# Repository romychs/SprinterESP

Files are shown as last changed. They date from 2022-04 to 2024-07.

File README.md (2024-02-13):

# Sprinter Wi-Fi

Проект ISA-8 платы для подключения Wi-Fi модуля ESP8266 к персональному любительскому компьютеру Sprinter.

Программное обеспечение, в настоящее время, в разработке.

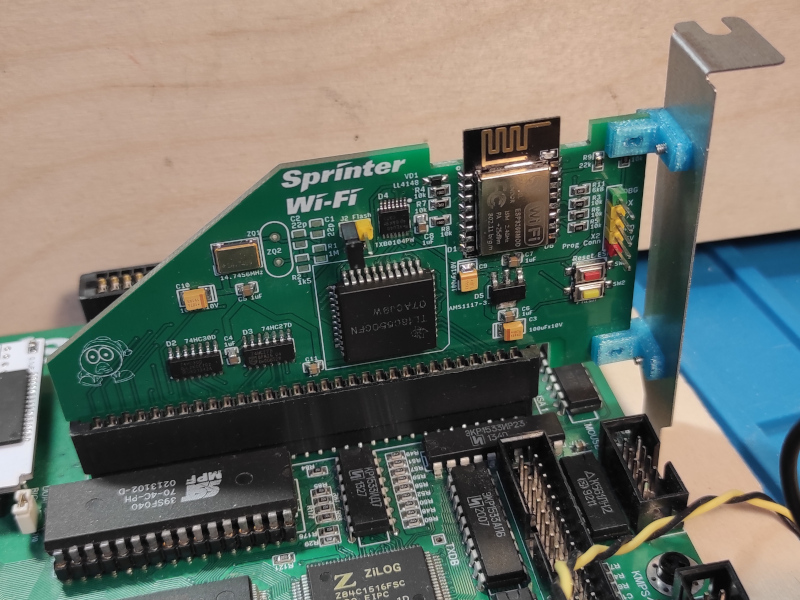
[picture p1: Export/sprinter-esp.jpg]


[Принципиальная схема](Export/Schematic_Sprinter-ESP_v1.0.4.pdf)

[Монтажная схема](Export/PCB_Sprinter-ESP-v1.0.4.pdf)

[Спринтер в Телеграм](https://t.me/zx_sprinter)

[Спринтер в Web](https://www.sprinter.ru/)

Часто, модули с Ali идут без прошивки ESP-AT. В таком виде карта Sprinter Wi-Fi работать не будет, модуль ESP нужно прошить. Инструкция в [документе](Docs/ESP-module-flashing.pdf).

## Изменения
* _v1.0.3_ Устранена ошибка с перепутанными сигналами RTS и CTS. В [документе](Docs/rts-cts-fix.pdf) описано, как это исправить на старых версиях платы.
* _v1.0.4_ Добавлен контакт VCC на разъеме X2 для подачи напряжения 5В при программировании ESP через внешний USB-TTL UART адаптер.
* _v1.0.5_ Косметические изменения для удобства пайки.

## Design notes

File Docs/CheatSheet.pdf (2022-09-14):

Порты UART
Порт ISA COM3 | 0x03E8
Базовый адрес портов карты ISA в
памяти

0xC3E8

Регистры UART
DLAB | A2 | A1 | A0 | Регистр
0 | 0 | 0 | 0 | RBR Read Buffer Reg, RO
0 | 0 | 0 | 0 | THR Transmitter hold reg, WO
0 | 0 | 0 | 1 | IER Interrupt enable reg
x | 0 | 1 | 0 | IIR Interrupt id reg, RO
x | 0 | 1 | 0 | FCR FIFO Control reg, WO
x | 0 | 1 | 1 | LCR Line Control reg
x | 1 | 0 | 0 | MCR Modem Contril reg
x | 1 | 0 | 1 | LSR Line Status reg
x | 1 | 1 | 0 | MSR Modem Status reg
x | 1 | 1 | 1 | SCR Scratch reg
1 | 0 | 0 | 0 | DLL Divisor latch LSB
1 | 0 | 0 | 1 | DLM Divisor latch MSB

LCR
1-0 00 — 5 bit data
01 — 6 bit data
10 — 7 bit data
11 — 8 bit data
2 | 0 — 1 stop bit
1 — 1,5 stop bits
3 | 0 — Disable parity, 1 — enable
4 | 0 — odd, 1 — even
5 | Stich patity 0 — dis, 1 -en
6 | break 0 — dis, 1 — en
7 | DLAB 0 — access receiver buffer; 1 -
access divisor latch

LSR
0 | DR Data Ready
1 | OE Overrun Error
2 | PE Parity Error
3 | FE Frame Error
4 | BI Break Interrupt
5 | THRE Transmitter Holding Register
6 | TEMT Transmitter Empty
7 | Error in RCVR FIFO

FCR
0 | FIFO Enable
1 | Receiver FIFO reset
2 | Transmitter FIFO reset
3 | DMA mode select
4 | reserved
5 | reserved
6 | Receiver trigger LSB
7 | Receiver trigger MSB

MCR
0 | DTR
1 | RTS
2 | OUT1 (Reset ESP)
3 | OUT2 (Program ESP)
4 | Loop
5 | AFE Autoflow control enable
6 | 0
7 | 0

IIR
0 | 0 — no pending interrupt
1 | Int ID bit 1
2 | Int ID bit 2
3 | Int ID bit 3
4 | 0
5 | 0
7-6 | Enable FIFOs int trigger lvl

Команды ESP AT
AT+RST | Сброс
AT+GMR | Получение версии прошивки
Wi-Fi
AT+CWMODE=1 | Включить режим станции
AT+CWJAP="SSID",
"password"

Подключение к сети

AT+CWLAP | Список доступных сетей
AT+CWQAP | Отсоединение от сети
AT+CWDHCPS? | Получить статус DHCP
AT+CWAUTOCONN=1 | Включить автоподключение к
WiFi. 0 — выкл.
AT+CIFSR | Показать IP-адрес
TCP/IP
AT+CIPSTATUS | Статус TCP/IP. 4-откл; 3-
подкл; 2-получен IP адр.
UART
ATE0 | Отключить эхо
AT+UART_CUR=1152 00,8,1,0,3 | Включить сколость 115200, 8 бит данных, без контроля четности,1 стоп-бит, RTS/CTS

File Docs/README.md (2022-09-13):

# Sprinter Wi-Fi

Инструкции к карте Sprinter Wi-Fi.

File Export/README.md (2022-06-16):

# Sprinter Wi-Fi

Схема и печатная плата в доступных для просмотра форматах.

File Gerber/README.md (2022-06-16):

# Sprinter Wi-Fi

При заказе платы, не забудте указать, что плата имеет контакты на краю платы и нужен скос, для удобства вставки платы в слот.

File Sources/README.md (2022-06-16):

# Sprinter Wi-Fi

Исходники проекта в [EasyIDA:](https://easyeda.com/)

*Как использовать:*

В редакторе, кликнуть на тулбаре в меню "Document" > "Open" > "EasyEDA Source", и выберите json-файл.

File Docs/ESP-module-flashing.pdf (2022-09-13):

# Прошивка модуля ESP-12 на карте Sprinter Wi-Fi

## Подключение

Для правильной работы карты Sprinter W-iFi, модуль, ESP-12 должен имень прошивку ESP-AT. Для прошивки понадобится преобразователь (адаптер) USB-UART, иногда они называются USB-TTL, их много на Ali, пойдет практически любой, с выходами, на 3,3В. Я пользуюсь преобразователями с чипами CH340, SiliconLabs CP210x. Драйверы для них уже встроены в Windows 10, Linux, ну и их не проблема найти для более старых версий Windows.

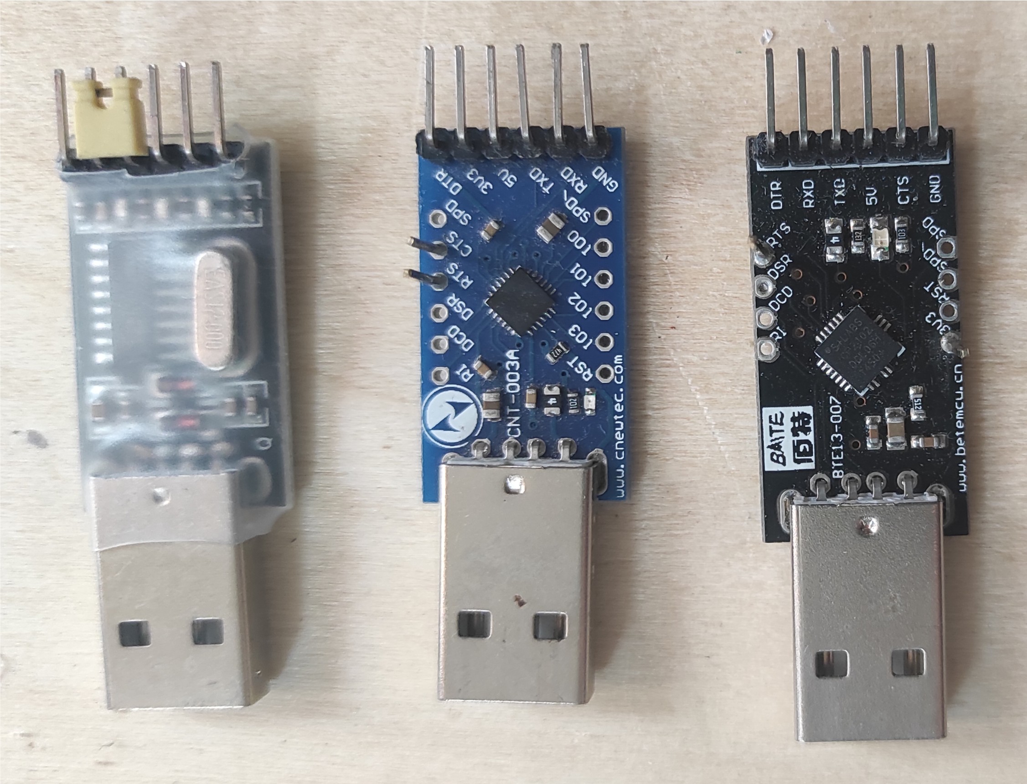
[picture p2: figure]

Подключаем преобразователь USB-UART к плате Sprinter Wi-Fi к разъему X2 (ProgConn) следующим образом:
TX → TX, RX→RX, GND→GND

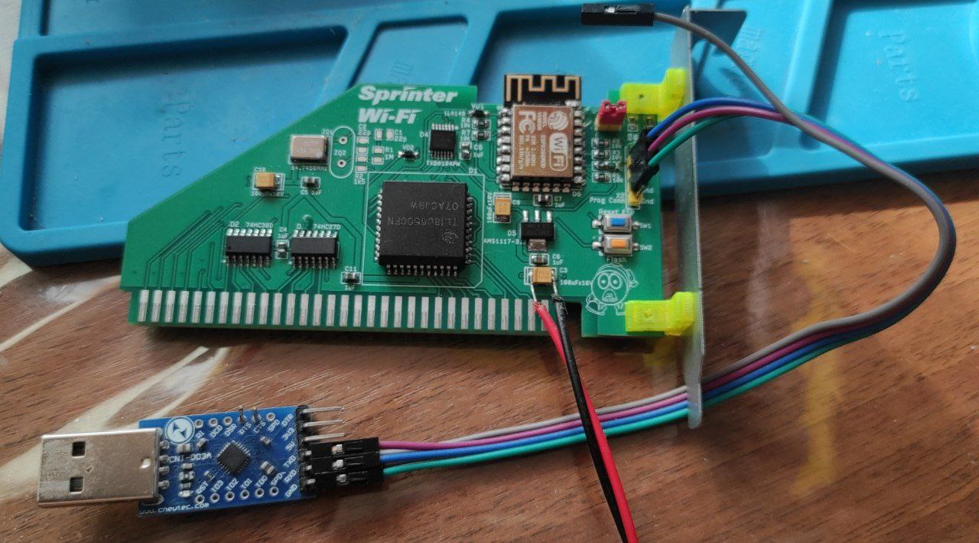
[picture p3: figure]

На плату Sprinter Wi-Fi нужно подать питание 5В. Можно запитать плату от слота самого Sprinter-а, можно временно подать питание, подпаявшись к электролитическому конденсатору C3. Не путайте полярность.

## Прошивка

Для прошивки ESP существует специальное ПО, от фирмы Espressif, называется оно Flash Download Tool. Найти его можно на сайте производителя, https://www.espressif.com/en/support/download/other-tools
Установки оно не требует, нужно просто скачать архив, распаковать и запустить исполняемый файл (flash_download_tool_x.x.x.exe).
Так же потребуются и файлы AT-firmware для прошивки модуля ESP. Найти более-менее свежий, подходящий для нашего модуля софт не простоб но можно. В архиве ESP8266_AT_V2.2.1.7z прилагается тот, который шью в модуль я. Мне удалось собрать и самую свежую прошивку, но я ее пока тестирую. Архив распакуйте в отдельную папку. Теперь подключаем питание к SprinterWiFi, вставляем адаптер USB-UART в USB-порт компьютера. Смотрим в диспетчере устройств, на каком COM-порту он работает:

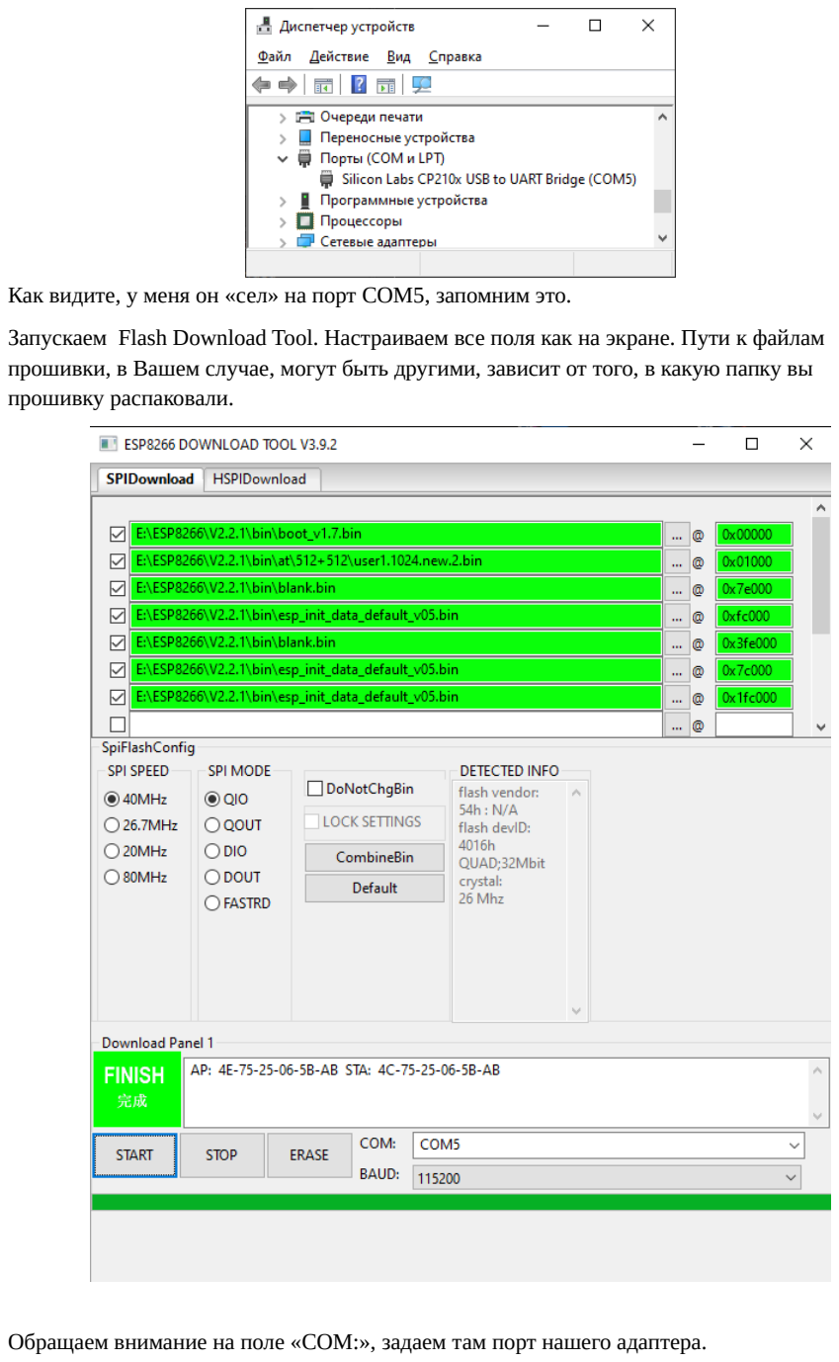
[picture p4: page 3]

Как видите, у меня он «сел» на порт COM5, запомним это.
Запускаем Flash Download Tool. Настраиваем все поля как на экране. Пути к файлам прошивки, в Вашем случае, могут быть другими, зависит от того, в какую папку вы прошивку распаковали.

Обращаем внимание на поле «COM:», задаем там порт нашего адаптера.

Теперь нажимаем кнопку Start, программа перейдет в режим прграммирования и будет ждать ESP.
Теперь переводим нашу карточку Sprinter Wi-Fi в режим программирования ESP:
1. Замыкаем джампер J2 (Flash) (Его расположение на плате может отличаться, в зависимости от версии)
2. Нажимаем кнопки SW1 + SW2
3. Отпускаем SW1 (Reset)
4. Через секунду-другую, отпускаем SW2 (Flash)
После перехода модуля ESP в режим программирования, программа его прошьет и появися надпись FINISH как на картинке.
После прошивки, не забудте снять джампер J2.
Отключаем от карточки все, что подключали, теперь она готова к работе.

Если есть желание, можете поэкспериментировать со сборкой новых прошивок ESP-AT сами: https://github.com/espressif/esp-at/tree/release/v2.2.0.0_esp8266

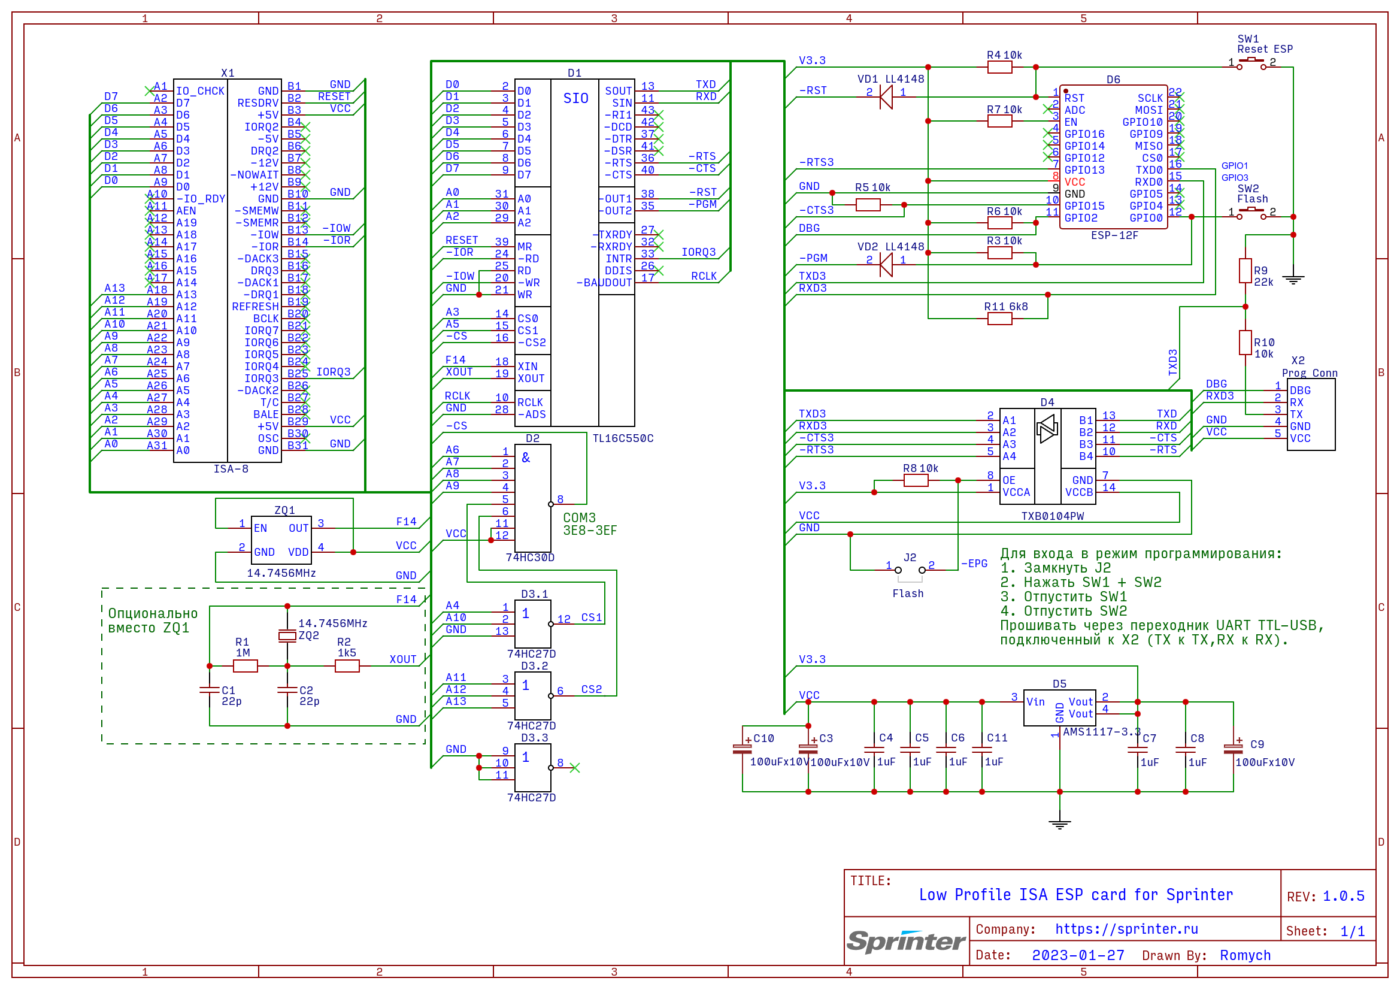
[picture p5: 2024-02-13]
Export/Schematic_Sprinter-ESP_v1.0.5.png

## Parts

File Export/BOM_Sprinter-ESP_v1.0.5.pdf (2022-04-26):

## BOM_Sprinter-ESP-PCB_2022-04-26

## Страница 1

Nпп. | Поз. | Наименование | Корпус | Колич. | Цена | Сумма
1 | D1 | TL16C550C | PLCC-44 | 1 | 2,6 | 2,6
2 | R8,R10,R3,R4,R5,R6,R7 | 10КΩ | 0805 | 7 | 0,01 | 0,07
3 | R11 | 6,8КΩ | 0805 | 1 | 0,01 | 0,01
4 | C1,C2 | 22пФ | 0805 | 2 | 0,01 | 0,02
5 | R1 | 1MΩ | 0805 | 1 | 0,01 | 0,01
6 | R2 | 1,5КΩ | 0805 | 1 | 0,01 | 0,01
7 | R9 | 22КΩ | 0805 | 1 | 0,01 | 0,01
8 | J2 | Джампер | РВК-ЕР 2p | 1 | 0,02 | 0,02
9 | SW1,SW2 | Тактовая кнопка SMD | 3x6x2,5мм | 2 | 0,06 | 0,12
10 | ZQ1 | Кварц ген. 14.7456MHz на 5В | SMD 7050 | 1 | 0,5 | 0,5
11 | X2 | Prog Conn | HDR-TH 5p | 1 | 0,02 | 0,02
12 | VD2,VD1 | LL4148 | SOD-123 | 2 | 0,02 | 0,04
13 | C11,C4,C5,C6,C7,C8 | 1uF | 0805 | 6 | 0,01 | 0,06
14 | C10,C3,C9 | 100uFx10V | CAP-SMD | 3 | 0,2 | 0,6
15 | D2 | 74HC30D | SOIC-14 | 1 | 0,26 | 0,26
16 | D3 | 74HC27D | SOIC-14 | 1 | 0,26 | 0,26
17 | D4 | TXB0104PW | TSSOP-14 | 1 | 0,3 | 0,3
18 | D5 | AMS1117-3.3 | SOT-223 | 1 | 0,1 | 0,1
19 | D6 | ESP8266MOD | ESP-12F | 1 | 1,7 | 1,7
20 | ZQ2 | Кварц. резонатор 1.8432MHz | HC-49U | 1 | 0,15 | 0,15
| | | PCB | 1 | 2,5 | 2,5
| | | Заглушка 8см | 1 | 0,4 | 0,4
| | | | | Итого | 9,76

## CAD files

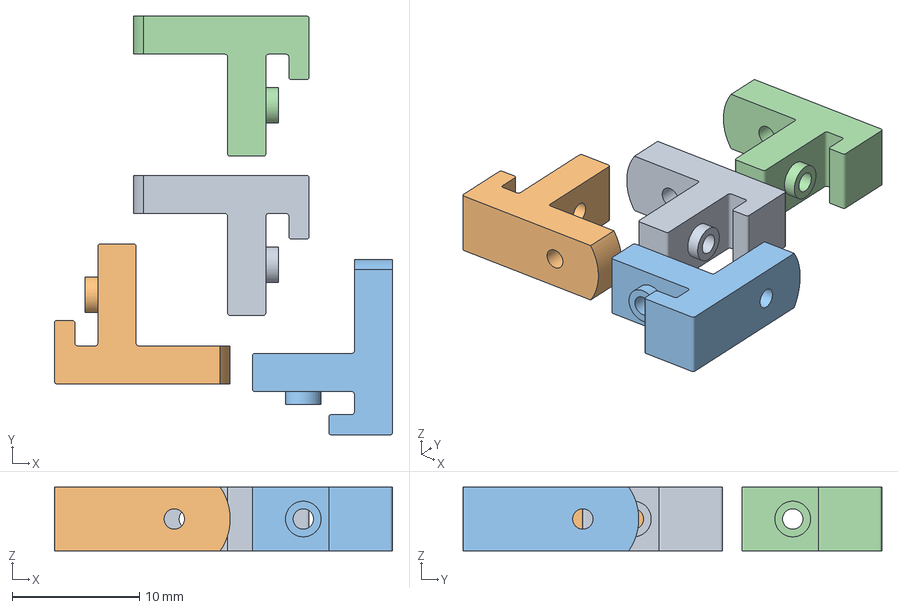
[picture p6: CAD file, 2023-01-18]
Export/ISA-Gacket_v2.3mf
26.5 x 32.9 x 5.00 mm
Body1.stl
Body1.stl(1)
Body1.stl(2)
Body1.stl(3)

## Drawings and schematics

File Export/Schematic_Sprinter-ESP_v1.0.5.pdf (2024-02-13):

### SIO D0 2

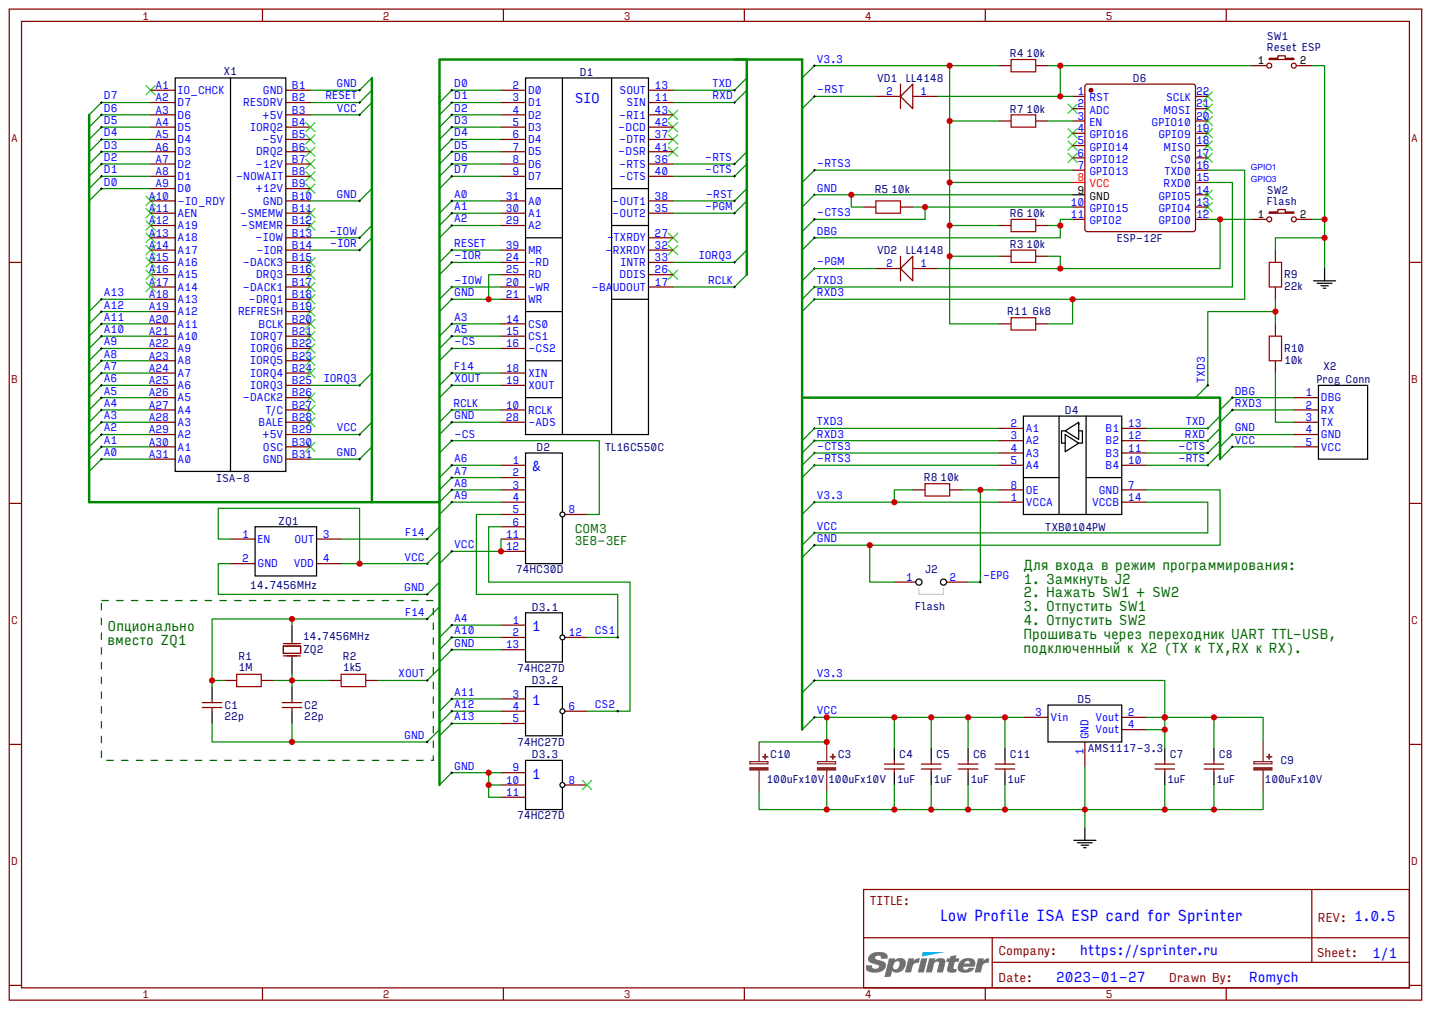
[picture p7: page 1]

2. Нажать SW1 + SW2
3. Отпустить SW1
4. Отпустить SW2
Прошивать через переходник UART TTL-USB, подключенный к X2 (TX к TX,RX к RX).

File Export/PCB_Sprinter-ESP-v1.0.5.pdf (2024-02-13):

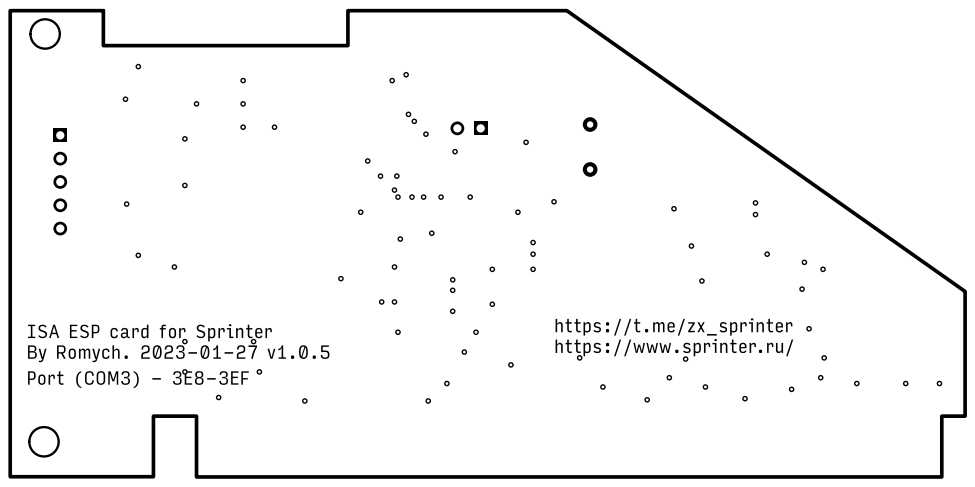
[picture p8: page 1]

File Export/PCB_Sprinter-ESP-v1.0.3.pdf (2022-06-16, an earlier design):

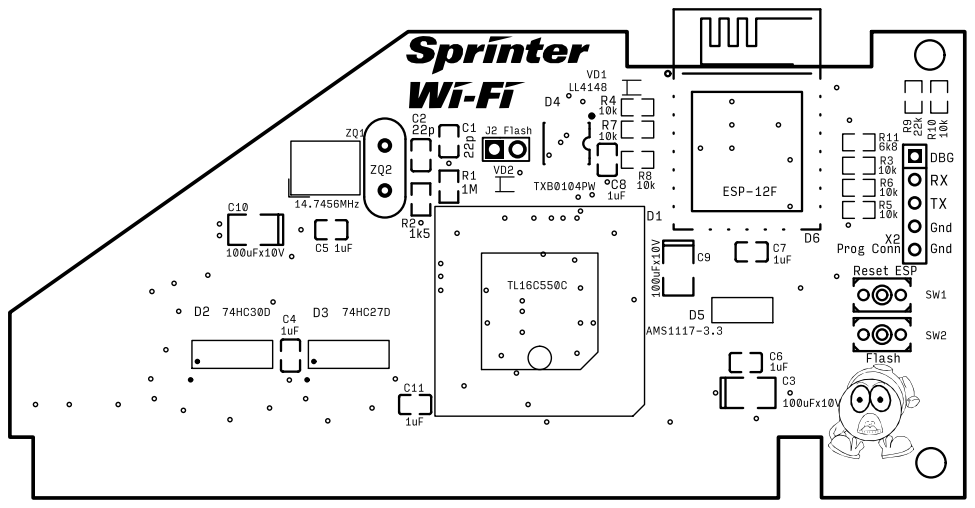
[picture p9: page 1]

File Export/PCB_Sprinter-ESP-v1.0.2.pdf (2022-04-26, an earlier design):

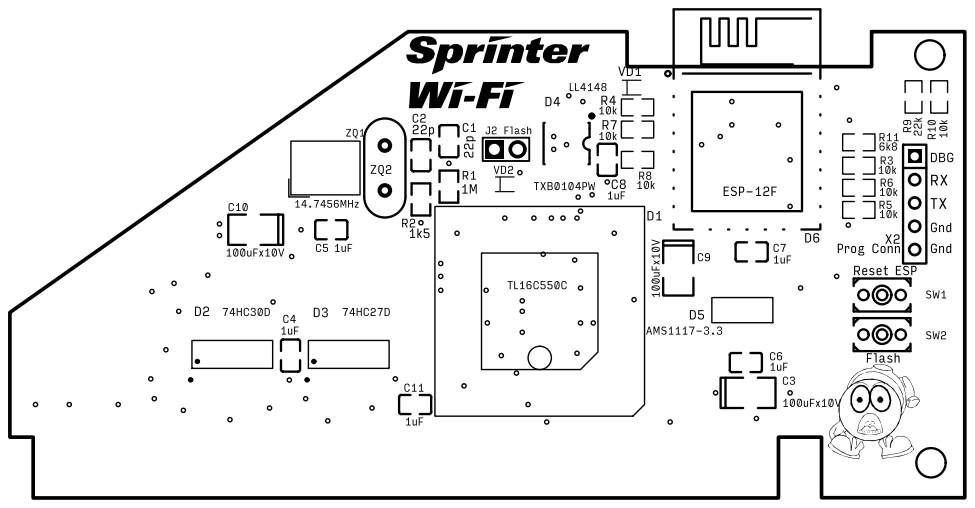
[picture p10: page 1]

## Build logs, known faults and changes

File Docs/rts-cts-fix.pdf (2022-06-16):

## По шагам

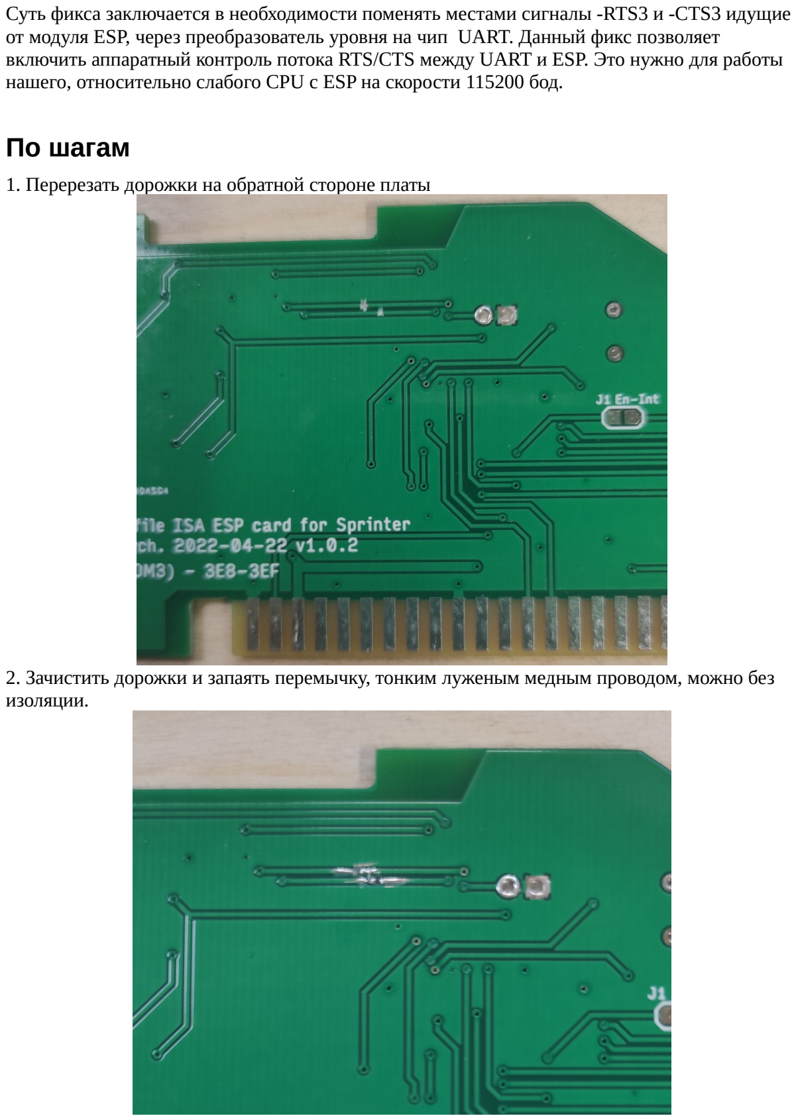
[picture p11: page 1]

Суть фикса заключается в необходимости поменять местами сигналы -RTS3 и -CTS3 идущие от модуля ESP, через преобразователь уровня на чип UART. Данный фикс позволяет включить аппаратный контроль потока RTS/CTS между UART и ESP. Это нужно для работы нашего, относительно слабого CPU с ESP на скорости 115200 бод.

1. Перерезать дорожки на обратной стороне платы
2. Зачистить дорожки и запаять перемычку, тонким луженым медным проводом, можно без изоляции.

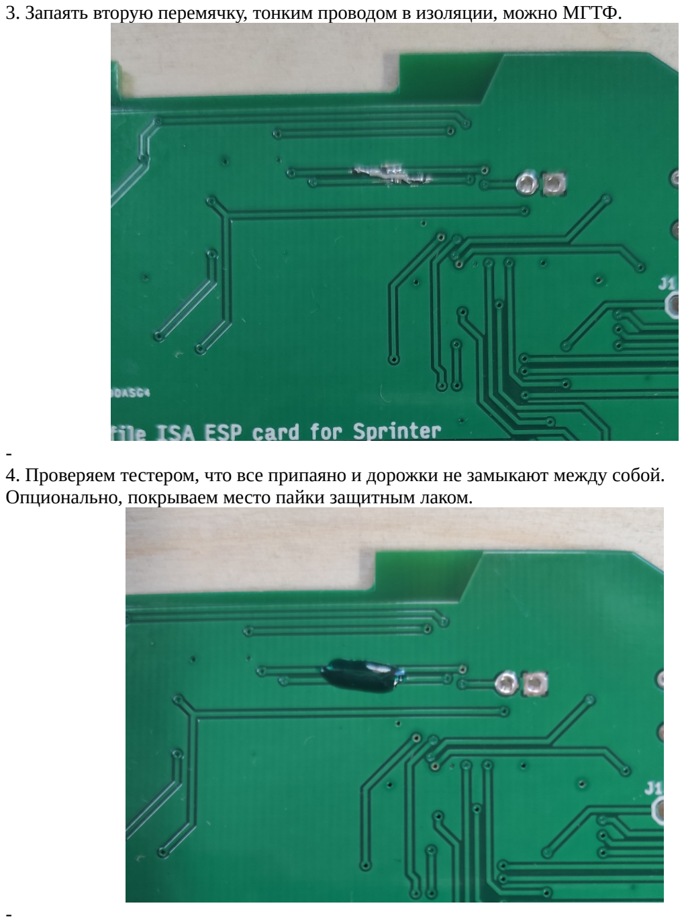
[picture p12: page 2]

3. Запаять вторую перемячку, тонким проводом в изоляции, можно МГТФ.
4. Проверяем тестером, что все припаяно и дорожки не замыкают между собой. Опционально, покрываем место пайки защитным лаком.

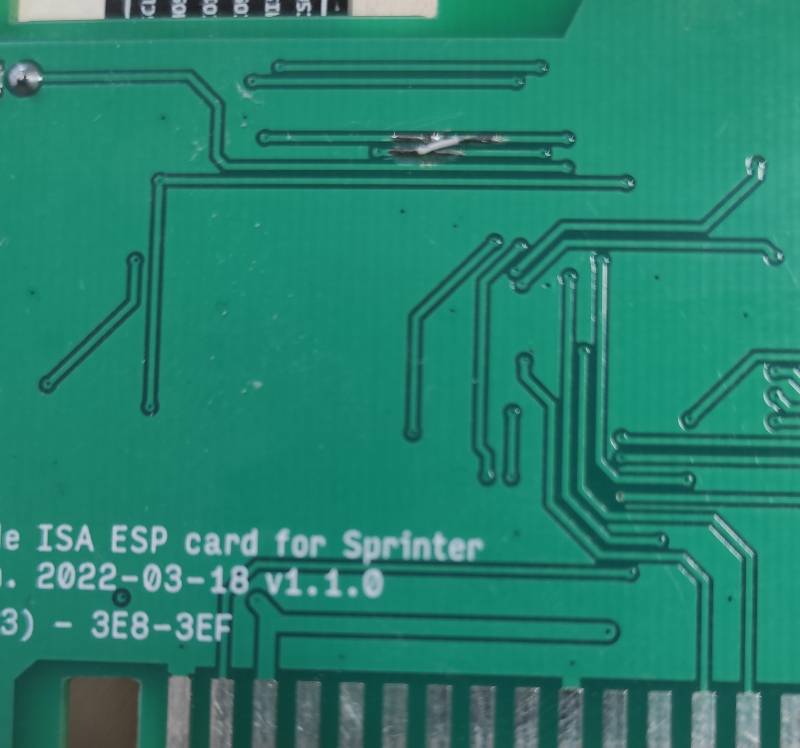
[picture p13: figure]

На нашей старой, отладочной плате, дорожки расположены чуть иначе:

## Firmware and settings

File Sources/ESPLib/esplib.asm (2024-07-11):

; ======================================================
; Library for Sprinter-WiFi ESP ISA Card
; By Roman Boykov. Copyright (c) 2024
; https://github.com/romychs
; License: BSD 3-Clause
; ======================================================

;ISA_BASE_A		EQU 0xC000        						; Базовый адрес портов ISA в памяти
PORT_UART		EQU 0x03E8        						; Базовый номер порта COM3
PORT_UART_A		EQU ISA_BASE_A + PORT_UART    			; Порты чипа UART в памяти 

; UART TC16C550 Registers in memory
REG_RBR 		EQU PORT_UART_A
REG_THR 		EQU PORT_UART_A
REG_IER 		EQU PORT_UART_A + 1
REG_IIR 		EQU PORT_UART_A + 2
REG_FCR			EQU PORT_UART_A + 2
REG_LCR			EQU PORT_UART_A + 3
REG_MCR 		EQU PORT_UART_A + 4
REG_LSR 		EQU PORT_UART_A + 5
REG_MSR 		EQU PORT_UART_A + 6
REG_SCR 		EQU PORT_UART_A + 7
REG_DLL 		EQU PORT_UART_A
REG_DLM 		EQU PORT_UART_A + 1
REG_AFR 		EQU PORT_UART_A + 2



; UART TC16C550 Register bits 
MCR_DTR         EQU	0x01
MCR_RTS         EQU	0x02
MCR_RST         EQU	0x04
MCR_PGM         EQU	0x08
MCR_LOOP        EQU	0x10
MCR_AFE         EQU	0x20
LCR_WL8         EQU	0x03								; 8 bits word len
LCR_SB2         EQU	0x04								; 1.5 or 2 stp bits
LCR_DLAB        EQU	0x80								; Enable Divisor latch
FCR_FIFO        EQU	0x01								; Enable FIFO for rx and tx
FCR_RESET_RX    EQU	0x02								; Reset Rx FIFO
FCR_RESET_TX    EQU	0x04								; Reset Tx FIFO
FCR_DMA         EQU	0x08								; Set -RXRDY, -TXRDY to "1"
FCR_TR1         EQU	0x00								; Trigger on 1 byte in fifo
FCR_TR4         EQU	0x40								; Trigger on 4 bytes in fifo
FCR_TR8         EQU	0x80								; Trigger on 8 bytes in fifo
FCR_TR14        EQU	0xC0								; Trigger on 14 bytes in fifo
LSR_DR          EQU	0x01								; Data Ready
LSR_OE          EQU	0x02								; Overrun Error
LSR_PE          EQU	0x04								; Parity Error
LSR_FE          EQU	0x08								; Framing Error
LSR_BI			EQU	0x10								; Break Interrupt
LSR_THRE        EQU	0x20								; Transmitter Holding Register Empty
LSR_TEMT        EQU	0x40								; Transmitter empty
LSR_RCVE        EQU	0x80								; Error in receiver FIFO

; Speed divider for UART 
BAUD_RATE 		EQU 115200                    			; Скорость соединения с ESP8266
XIN_FREQ 		EQU 14745600                  			; Частота генератора для TL16C550
DIVISOR 		EQU XIN_FREQ / (BAUD_RATE * 16)  		; Делитель частоты для передачи/приема данных

RS_BUFF_SIZE 	EQU	2048								; Receive buffer size
MAX_BUFF_SIZE 	EQU	16384

LSTR_SIZE 		EQU	20									; Size of buffer for last response line
LF 				EQU 0x0A
CR 				EQU	0x0D

; -- 
RES_OK			EQU 0
RES_ERROR		EQU 1
RES_FAIL		EQU 2
RES_TX_TIMEOUT 	EQU 3
RES_RS_TIMEOUT	EQU 4
RES_CONNECTED	EQU 5
RES_NOT_CONN	EQU 6
RES_ENABLED		EQU 7
RES_DISABLED 	EQU	8



	MODULE WIFI

; -- UART Registers offset

_RBR 			EQU	0
_THR 			EQU	0
_IER 			EQU	1
_IIR 			EQU	2
_FCR			EQU	2
_LCR			EQU	3
_MCR 			EQU	4
_LSR 			EQU	5
_MSR 			EQU	6
_SCR 			EQU	7
_DLL 			EQU	0
_DLM 			EQU	1
_AFR 			EQU	2


; ------------------------------------------------------
; Find TL550C in ISA slot
; Out: CF=1 - Not found, CF=0 - ISA.ISA_SLOT found in slot
; ------------------------------------------------------
UART_FIND
	PUSH	HL
	XOR 	A
	CALL	UT_T_SLOT
	JR		Z, UF_T_FND
	LD		A,1
	CALL	UT_T_SLOT
	JR		Z, UF_T_FND
	SCF
UF_T_FND
	POP		HL
	RET

; Test slot, A - ISA Slot no. 0 or 1
UT_T_SLOT
	; check IER hi bits, will be 0
	LD		(ISA.ISA_SLOT), A
	LD		HL, REG_IER
	CALL	UART_READ
	AND		0xF0
	RET		NZ

	; check SCR register
	LD		DE,0x5555
	CALL	CHK_SCR
	RET		NZ
	LD		DE,0xAAAA
	CALL	CHK_SCR
	RET

CHK_SCR	
	LD		HL, REG_SCR
	CALL	UART_WRITE
	CALL	UART_READ
	CP		D
	RET



; ------------------------------------------------------
; Init UART device TL16C550
; ------------------------------------------------------
UART_INIT
	PUSH	AF, IX

	CALL 	ISA.ISA_OPEN
	LD		IX, PORT_UART_A
	LD		A, FCR_TR8 | FCR_FIFO						; Enable FIFO buffer, trigger to 14 byte
	LD		(IX+_FCR),A									
	XOR 	A
	LD 		(IX+_IER), A								; Disable interrupts

	; Set 8bit word and Divisor for speed
	LD 		A, LCR_DLAB | LCR_WL8
	LD 		(IX+_LCR), A								; Enable Baud rate latch
	LD 		A, DIVISOR
	LD 		(IX+_DLL), A								; 8 - 115200
	XOR 	A
	LD		(IX+_DLM), A
	LD 		A, LCR_WL8									; 8bit word, disable latch
	LD 		(IX+_LCR), A
	CALL 	ISA.ISA_CLOSE

	POP 	IX,AF
	RET

; ------------------------------------------------------
; Read TL16C550 register
;   Inp: HL - register
;   Out: A - value from register
; ------------------------------------------------------
UART_READ
	CALL 	ISA.ISA_OPEN
	LD 		A, (HL)
	CALL 	ISA.ISA_CLOSE
	RET

; ------------------------------------------------------
; Write TL16C550 register
;   Inp: HL - register, E - value
; ------------------------------------------------------
UART_WRITE            
	CALL	ISA.ISA_OPEN
	LD 		(HL), E
	CALL 	ISA.ISA_CLOSE
	RET

; ------------------------------------------------------
; Wait for transmitter ready
;   Out: CF=1 - tr not ready,  CF=0 ready
; ------------------------------------------------------
UART_WAIT_TR
	CALL	ISA.ISA_OPEN
	CALL	UART_WAIT_TR_INT
	CALL	ISA.ISA_CLOSE
	RET

;
; Wait, without open/close ISA
;
UART_WAIT_TR_INT
	PUSH	AF, BC, HL
	LD BC,	500
	LD HL, 	REG_LSR
WAIT_TR_BZY           
	LD 		A,(HL)
	AND 	A, LSR_THRE
	JR 		NZ,WAIT_TR_RDY
	CALL	UTIL.DELAY_100uS							; ~11 bit tx delay
	DEC 	BC
	LD 		A, C
	OR		B	
	JR 		NZ,WAIT_TR_BZY
	SCF
WAIT_TR_RDY
	POP 	HL, BC, AF
	RET

; ------------------------------------------------------
; Transmit byte 
; Inp: E - byte
; Out: CF=1 - Not ready
; ------------------------------------------------------
UART_TX_BYTE
	CALL 	UART_WAIT_TR
	JP		C, UTB_NOT_R
	LD		HL, REG_THR
	CALL 	UART_WRITE
	XOR		A
UTB_NOT_R
	RET

; ------------------------------------------------------
;  Transmit buffer 
;	Inp: HL -> buffer, BC - size
;   Out: CF=0 - Ok, CF=1 - Timeout
; ------------------------------------------------------
UART_TX_BUFFER
	PUSH	BC,DE,HL
	LD		DE, REG_THR
	CALL	ISA.ISA_OPEN
UTX_NEXT	
	; buff not empty?
	LD		A, B
	OR		C
	JR		Z,UTX_EMP
	; check transmitter ready
	CALL	UART_WAIT_TR_INT
	JR		C, UTX_TXNR
	; transmitt byte
	LD		A,(HL)
	INC		HL
	LD		(DE),A
	DEC		BC
	JR		UTX_NEXT
	; CF=0
UTX_EMP	
	AND		A
UTX_TXNR
	CALL	ISA.ISA_CLOSE
	POP		HL,DE,BC
	RET

; ------------------------------------------------------
;  Transmit zero ended string
;	Inp: HL -> buffer
;   Out: CF=0 - Ok, CF=1 - Timeout
; ------------------------------------------------------
UART_TX_STRING
	PUSH	DE,HL
	LD		DE, REG_THR
	CALL	ISA.ISA_OPEN
UTXS_NEXT
	LD 		A,(HL)
	AND		A
	JR		Z,UTXS_END
	; check transmitter ready
	CALL	UART_WAIT_TR_INT
	JR		C, UTXS_TXNR
	; transmitt byte
	LD		A,(HL)
	INC		HL
	LD		(DE),A
	JR		UTXS_NEXT
	; CF=0
UTXS_END
	AND		A
UTXS_TXNR
	CALL	ISA.ISA_CLOSE
	POP		HL,DE
	RET




; ------------------------------------------------------
; Empty receiver FIFO buffer
; ------------------------------------------------------
UART_EMPTY_RS
	PUSH 	DE, HL
	LD 		E, FCR_TR8 | FCR_RESET_RX | FCR_FIFO
	LD		HL, REG_FCR
	CALL	UART_WRITE
	POP 	HL, DE
	RET
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

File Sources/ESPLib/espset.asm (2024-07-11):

; ======================================================
; ESPSET for Sprinter-WiFi for Sprinter computer
; By Roman Boykov. Copyright (c) 2024
; https://github.com/romychs
; License: BSD 3-Clause
; ======================================================


; Set to 1 to turn debug ON with DeZog VSCode plugin
; Set to 0 to compile .EXE
DEBUG               EQU 0

; Set to 1 to output TRACE messages
TRACE               EQU 1

; Version of EXE file, 1 for DSS 1.70+
EXE_VERSION         EQU 0

; Timeout to wait ESP response
DEFAULT_TIMEOUT		EQU	2000

    SLDOPT COMMENT WPMEM, LOGPOINT, ASSERTION

    DEVICE NOSLOT64K

    IF  DEBUG == 1
		INCLUDE "dss.asm"
		DB 0
		ALIGN 16384, 0
        DS 0x80, 0
    ENDIF

	INCLUDE "macro.inc"
	INCLUDE "dss.inc"
	INCLUDE "sprinter.inc"

	MODULE MAIN

    ORG 0x8080

; ------------------------------------------------------
EXE_HEADER
    DB  "EXE"
    DB  EXE_VERSION                                     ; EXE Version
    DW  0x0080                                          ; Code offset
    DW  0
    DW  0                                               ; Primary loader size
    DW  0                                               ; Reserved
    DW  0
    DW  0
    DW  START                                           ; Loading Address
    DW  START                                           ; Entry Point
    DW  STACK_TOP                                       ; Stack address
    DS  106, 0                                          ; Reserved

    ORG 0x8100
@STACK_TOP
	
; ------------------------------------------------------
START
	
    IF DEBUG == 1
    ; LD 		IX,CMD_LINE1
	LD		SP, STACK_TOP
    ENDIF


	CALL 	ISA.ISA_RESET

    PRINTLN MSG_START

	CALL	FIND_SWF

	; Turn local echo Off
	CALL	INIT_ESP

	; Display main menu to make selection
MENU_AGAIN
	CALL	SELECT_MAIN_MENU

	; Do somethink with selected item
	AND 	A
	JR		Z, MENU_EXIT
	DEC		A
	JP		Z, MENU_SELECT_WIFI
	DEC		A
	JP		Z, MENU_CONFIGURE_IP
	DEC		A
	JP		Z, MENU_DISPLAY_INFO
	JP		MENU_AGAIN

MENU_EXIT
	LD		B,0
	JP		EXIT


MENU_SELECT_WIFI
MENU_CONFIGURE_IP
MENU_DISPLAY_INFO
	JP		MENU_AGAIN

NO_TL_FOUND
	PRINTLN MSG_SWF_NOF
	LD		B,2
	JP		EXIT


CHECK_ERROR
	RET		NC
	ADD		A,'0'
	LD		(COMM_ERROR_NO), A
	PRINTLN	MSG_COMM_ERROR
	LD		B,3
	POP		HL											; ret addr reset

EXIT	
    LD		C,DSS_EXIT
    RST		DSS

FIND_SWF
	; Find Sprinter-WiFi
	CALL    WIFI.UART_FIND
	JP		C, NO_TL_FOUND
	LD		A,(ISA.ISA_SLOT)
	ADD		A,'1'
	LD      (MSG_SLOT_NO),A
	PRINTLN	MSG_SWF_FOUND
    LD      C,DSS_PCHARS
    RST     DSS
	RET
	


; ------------------------------------------------------
; Init basic parameters of ESP
; ------------------------------------------------------
INIT_ESP
	PUSH	BC, DE
	LD		DE, WIFI.RS_BUFF
	LD		BC, DEFAULT_TIMEOUT

   	TRACELN	MSG_ECHO_OFF
	SEND_CMD CMD_ECHO_OFF

   	TRACELN MSG_STATIOJN_MODE
	SEND_CMD CMD_STATION_MODE

   	TRACELN MSG_NO_SLEEP
	SEND_CMD CMD_NO_SLEEP

   	TRACELN MSG_SET_UART
	SEND_CMD CMD_SET_SPEED

   	TRACELN MSG_SET_OPT
	SEND_CMD CMD_CWLAP_OPT
	POP		DE,BC
	RET

; ------------------------------------------------------
; Set DHCP mode
; Out: CF=1 if error
; ------------------------------------------------------
SET_DHCP_MODE
	PUSH	BC,DE
	LD		DE, WIFI.RS_BUFF
	LD		BC, DEFAULT_TIMEOUT
	TRACELN MSG_SET_DHCP
	SEND_CMD CMD_SET_DHCP
	POP		DE,BC
	RET



; ------------------------------------------------------
;  Output main menu to select user action
;  Ret: A = selected menu item
; ------------------------------------------------------
SELECT_MAIN_MENU
	PUSH	BC
	PRINTLN MSG_MAIN_MENU
SMM_L1
	PRINT MSG_ENT_NO
	; SCANF
	LD		C, DSS_ECHOKEY
	RST		DSS
	SUB		'0'
	; Test A in range [0..3]
	AND		A
	JP		M, SMM_L1
	CP		4
	JP 		P, SMM_L1
	POP		BC
	RET

; ------------------------------------------------------
; Messages	DB "\r\n1 - Select WiFi Network\r\n"
   	DB "2 - Configure IP parameters\r\n"
   	DB "3 - Display info\r\n"
	DB "0 - Exit",0

; ------------------------------------------------------
MSG_START
	DB "Setup for Sprinter-WiFi by Sprinter Team, ", __DATE__ ,"\r\n", 0

MSG_SWF_NOF
	DB "Sprinter-WiFi not found!",0

MSG_SWF_FOUND
	DB "Sprinter-WiFi found in ISA#"
MSG_SLOT_NO
	DB "n slot.",0

MSG_COMM_ERROR
	DB "Error communication with Sprinter-WiFi #"
COMM_ERROR_NO
	DB "n!",0

MSG_MAIN_MENU
	DB "\r\n1 - Select WiFi Network\r\n"
   	DB "2 - Configure IP parameters\r\n"
   	DB "3 - Display info\r\n"
	DB "0 - Exit",0

MSG_ENT_NO
	DB "\r\nEnter number 0..3: ",0
; ------------------------------------------------------
; Debug messages
; ------------------------------------------------------
	IF TRACE

MSG_ECHO_OFF 
	DB "Echo off",0

MSG_STATIOJN_MODE
	DB "Station mode",0

MSG_NO_SLEEP
	DB "No sleep",0

MSG_SET_UART
	DB "Setup uart",0

MSG_SET_OPT
	DB "Set options",0

MSG_SET_DHCP
	DB	"Set DHCP mode",0

	ENDIF


; ------------------------------------------------------
; Commands
; ------------------------------------------------------
CMD_SET_SPEED 
	DB	"AT+UART_CUR=115200,8,1,0,3\r\n",0	
CMD_ECHO_OFF
	DB	"ATE0\r\n",0
CMD_STATION_MODE 
	DB	"AT+CWMODE=1\r\n",0
CMD_NO_SLEEP
	DB	"AT+SLEEP=0\r\n",0
CMD_CHECK_CONN_AP
	DB	"AT+CWJAP?\r\n",0
CMD_CWLAP_OPT
	DB	"AT+CWLAPOPT=1,23\r\n",0
CMD_GET_AP_LIST
	DB "AT+CWLAP\r\n",0
CMD_GET_DHCP
	DB "AT+CWDHCP?\r\n",0
CMD_SET_DHCP
	DB	"AT+CWDHCP=1,1\r\n",0
CMD_GET_IP
	DB "AT+CIPSTA?\r\n",0
LINE_END 
	DB "\r\n",0



	IF DEBUG == 1
CMD_TEST1	DB "ATE0\r\n",0	
BUFF_TEST1	DS RS_BUFF_SIZE,0
	ENDIF

	ENDMODULE

	INCLUDE "util.asm"
	INCLUDE "isa.asm"
	INCLUDE "esplib.asm"

    END MAIN.START

    ; PUSH	IX                                          ; IX ptr to cmd line
    ; POP		HL
    ; INC		HL                                          ; Skip size of Command line
    ; LD		DE,ZIP_FILE
    ; CALL 	GET_CMD_PARAM
    ; JR		C,INVALID_CMDLINE
    ; LD		DE,FILES_TO_ZIP
    ; CALL	GET_CMD_PARAM
    ; JR		C,INVALID_CMDLINE

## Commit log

2022-04-26 fix Readme and add BOM
2022-09-13 ESP module flashing instruction
    [ISA-Gacket.3mf]
2023-01-18 Rev 1.0.4. VCC pin on X2
    [ISA-Gacket.3mf, ISA-Gacket_v2.3mf]
2023-01-18 Sources an gerbers v1.0.4
2024-02-13 Footprint changes for better soldering
